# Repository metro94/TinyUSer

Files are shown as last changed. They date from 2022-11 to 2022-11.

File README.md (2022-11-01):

# TinyUSer - USB to Serial powered by CH340X

## Introduction

A tiny USB-to-Serial baord in just ~10x18 mm^2, powered by CH340X with *DTR#* supported.

## 3D Rendering View

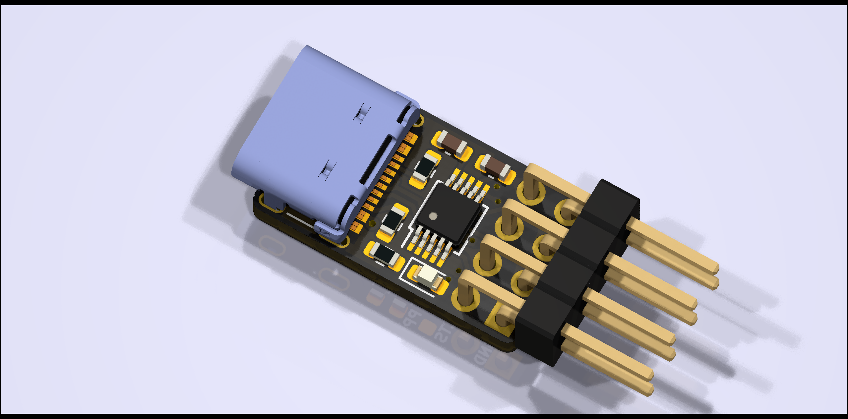
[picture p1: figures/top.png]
Top View


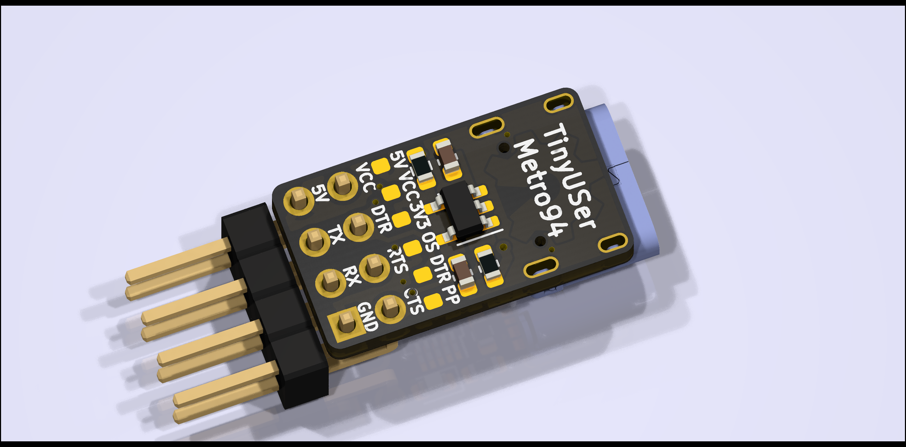
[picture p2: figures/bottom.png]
Bottom View


## License

[CERN-OHL-P](LICENSE)

## EDA

KiCad 6.0.6

## Usages

This PCB can be used with both CH340E and CH340X. For CH340X, *TNOW* can be replaced by *DTR#*, which is useful for UART download purpose.

If 5V IO voltage level is desired, *5V* to *VCC* shall be shorten by 0Ω resistor, and *R3* shall **NOT** be connected. LDO is not required and can be left unconnected.

If 3.3V IO voltage level is desired, *3V3* to *VCC* shall be shorten by 0Ω resistor, and *R3* shall be connected. LDO is required and two 1μF capacitors should be connected.

If *DTR#* is desired, *DTR* shall be connected to *OS* (Open-Source) or *PP* (Push-Pull) by 4.7kΩ resistor, otherwise left unconnected.

### Schematics

[TinyUSer Schematic](schematics/TinyUSer.pdf)

### BOM

[TinyUSer BOM](https://metro94.github.io/TinyUSer/bom.html)

### Product Page

[USB to Serial Port Chip CH340 - NanjingQinhengMicroelectronics](http://www.wch-ic.com/products/CH340.html)

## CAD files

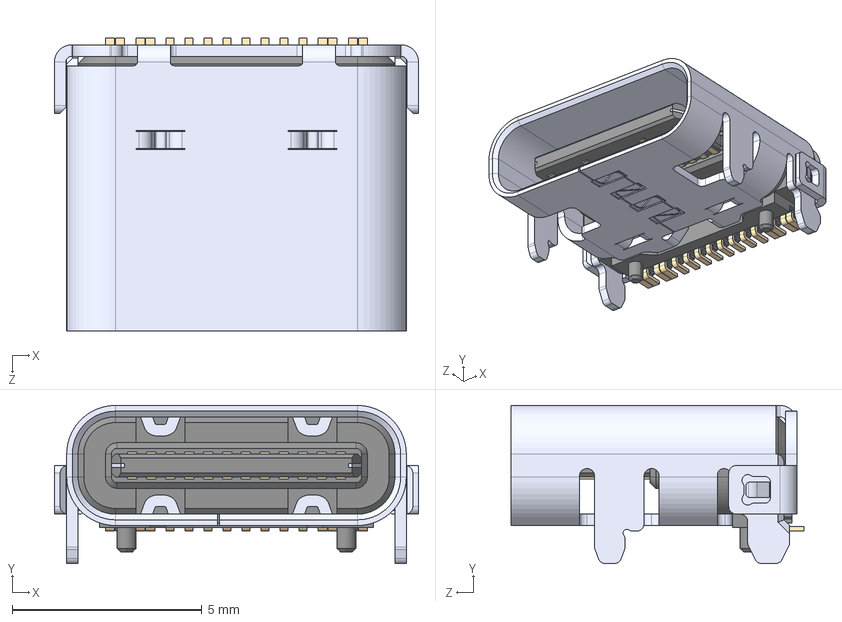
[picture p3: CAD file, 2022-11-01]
USB4105_GF_A.STEP
9.58 x 4.16 x 7.71 mm

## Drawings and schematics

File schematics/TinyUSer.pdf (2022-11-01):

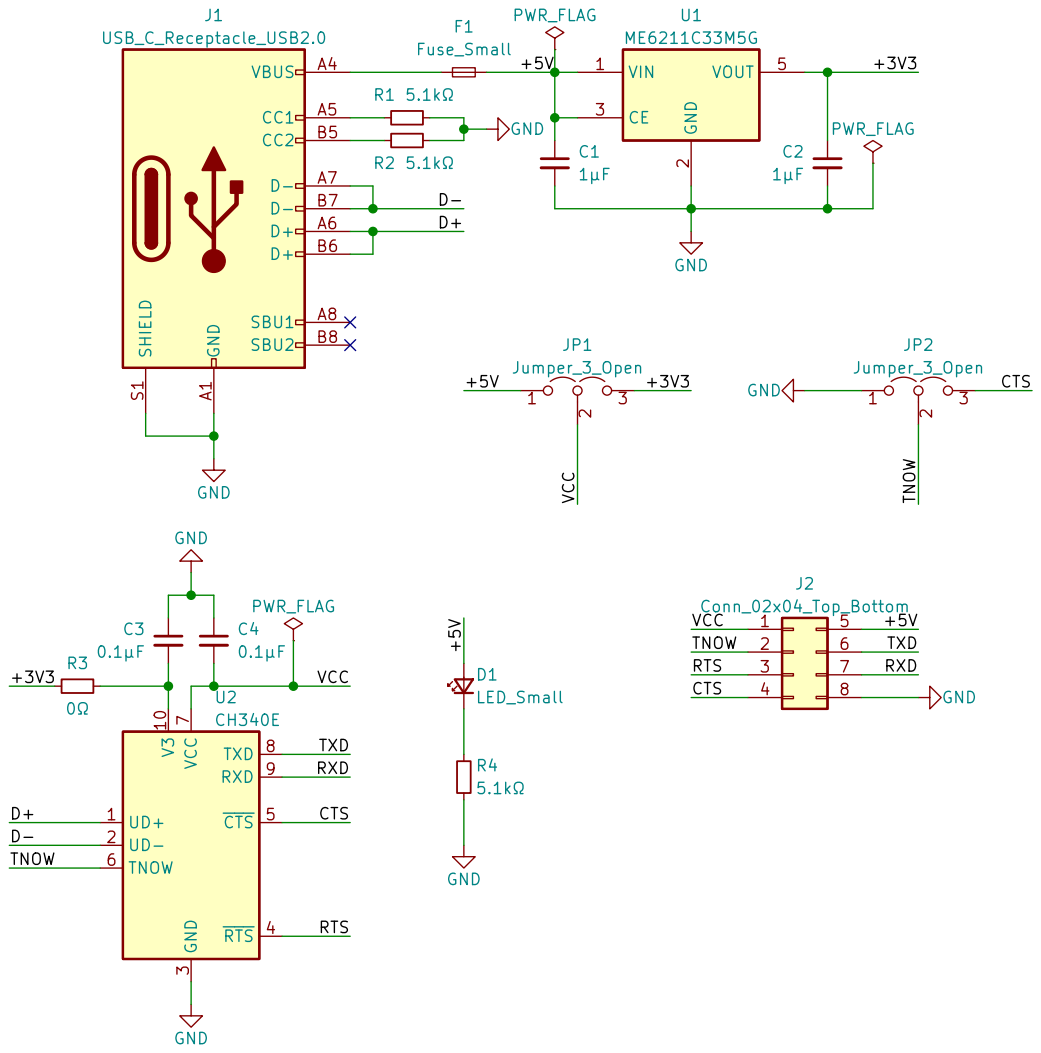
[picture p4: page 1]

2 CE 3 VOUT 5 U1 ME6211C33M5G GND A1 VBUS A4 CC1 A5 D+ A6 D- A7 SBU1 A8 CC2 B5 D+ B6 D- B7 SBU2 B8 SHIELD S1

3 ~{RTS} 4 ~{CTS} 5 TNOW 6 VCC

File: TinyUSer.kicad_sch Sheet: / Metro94 <flattiles@gmail.com>

Id: 1/1 Title: TinyUSer - USB to Serial powered by CH340X

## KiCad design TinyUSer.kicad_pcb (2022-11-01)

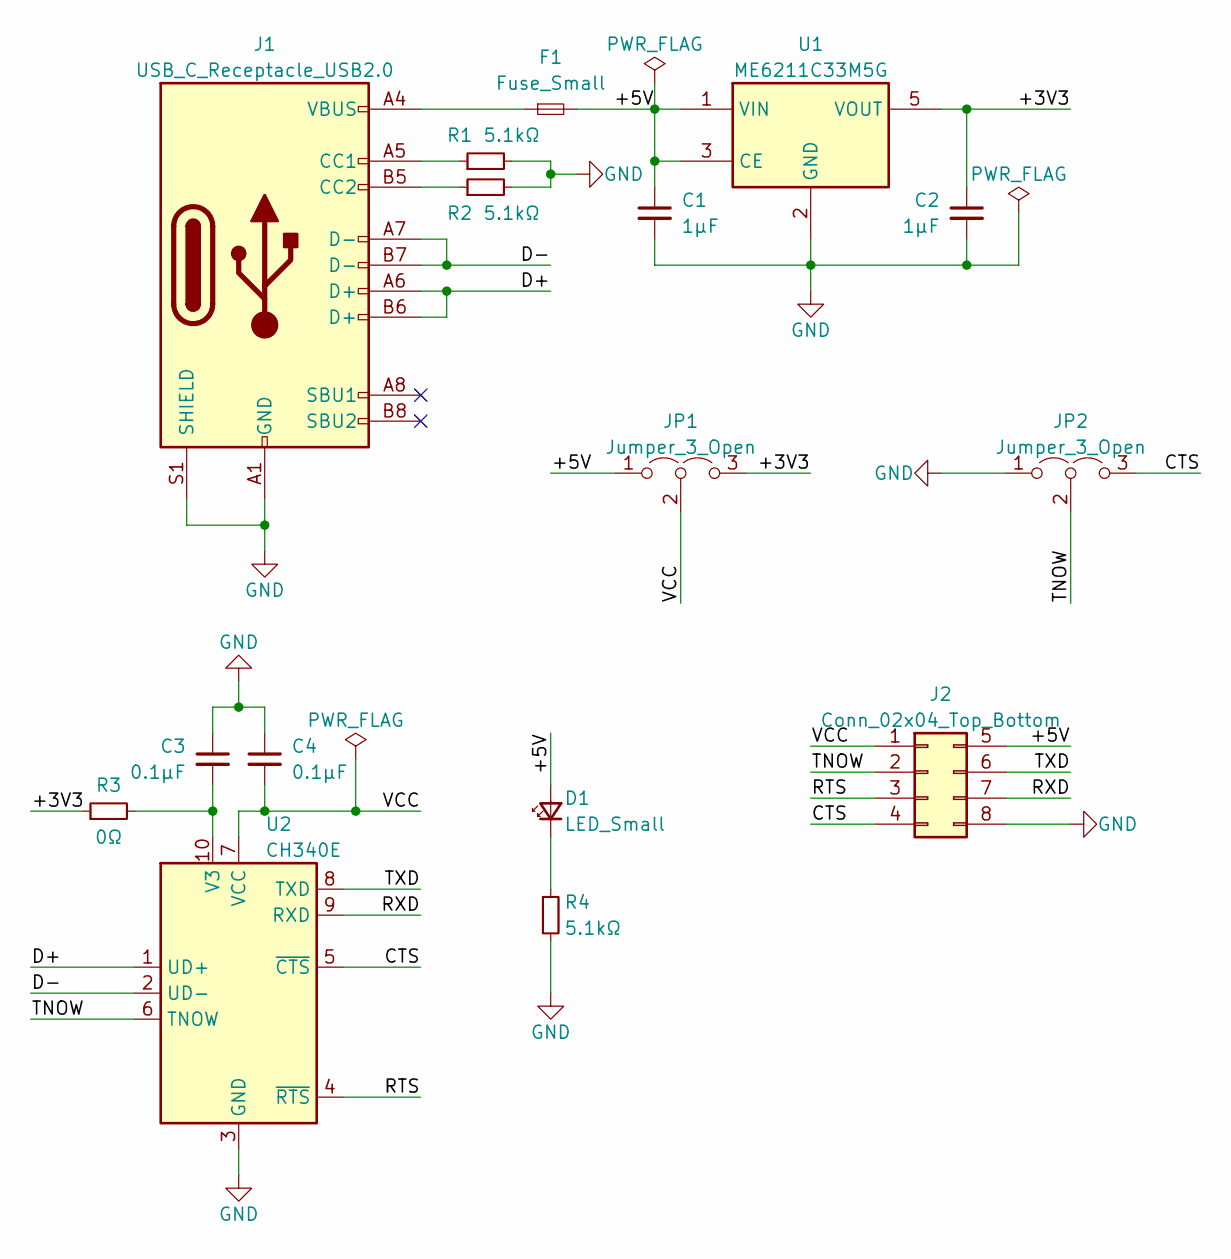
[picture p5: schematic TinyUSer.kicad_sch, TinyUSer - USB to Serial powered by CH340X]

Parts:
C1, C2: 1μF; C_0603_1608Metric
C3, C4: 0.1μF; C_0603_1608Metric
D1: LED_Small; LED_0603_1608Metric
F1: Fuse_Small; Fuse_0603_1608Metric
J1: USB_C_Receptacle_USB2.0; USB_C_Receptacle_Palconn_UTC16-G
J2: Conn_02x04_Top_Bottom; Pin_2x04_P2.54mm_NoSilkscreen
JP1, JP2: Jumper_3_Open; Jumper-3
R1, R2, R4: 5.1kΩ; R_0603_1608Metric
R3: 0Ω; R_0603_1608Metric
U1: ME6211C33M5G; SOT-23-5
U2: CH340E; MSOP-10_3x3mm_P0.5mm

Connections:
/+3V3: C2.1, JP1.3 (B), R3.1, U1.5 (VOUT)
/+5V: C1.1, D1.2 (A), F1.2, J2.5, JP1.1 (A), U1.1 (VIN), U1.3 (CE)
/CTS: J2.4, JP2.3 (B), U2.5 (~CTS)
/D+: J1.A6 (D+), J1.B6 (D+), U2.1 (UD+)
/D-: J1.A7 (D-), J1.B7 (D-), U2.2 (UD-)
/RTS: J2.3, U2.4 (~RTS)
/RXD: J2.7, U2.9 (RXD)
/TNOW: J2.2, JP2.2 (C), U2.6 (TNOW)
/TXD: J2.6, U2.8 (TXD)
/VCC: C4.2, J2.1, JP1.2 (C), U2.7 (VCC)
GND: C1.2, C2.2, C3.1, C4.1, J1.A1 (GND), J1.A12 (GND), J1.B1 (GND), J1.B12 (GND), J1.S1 (SHIELD), J2.8, JP2.1 (A), R1.2, R2.2, R4.2, U1.2 (GND), U2.3 (GND)
unnamed: C3.2, R3.2, U2.10 (V3)
unnamed: D1.1 (K), R4.1
unnamed: F1.1, J1.A4 (VBUS), J1.A9 (VBUS), J1.B4 (VBUS), J1.B9 (VBUS)
unnamed: J1.A5 (CC1), R1.1
unnamed: J1.B5 (CC2), R2.1

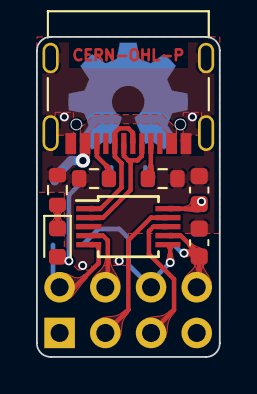
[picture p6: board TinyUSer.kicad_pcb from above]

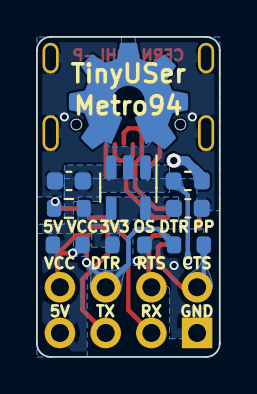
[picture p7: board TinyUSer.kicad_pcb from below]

Board: 2 copper layers, 10.2 x 17.8 mm, 16 parts (7 on the bottom side), 16 nets.
